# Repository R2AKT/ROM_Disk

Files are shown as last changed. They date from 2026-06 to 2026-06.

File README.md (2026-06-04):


License addendum - https://github.com/R2AKT/ROM_Disk/blob/main/Addendum.txt
# ROM_Disk

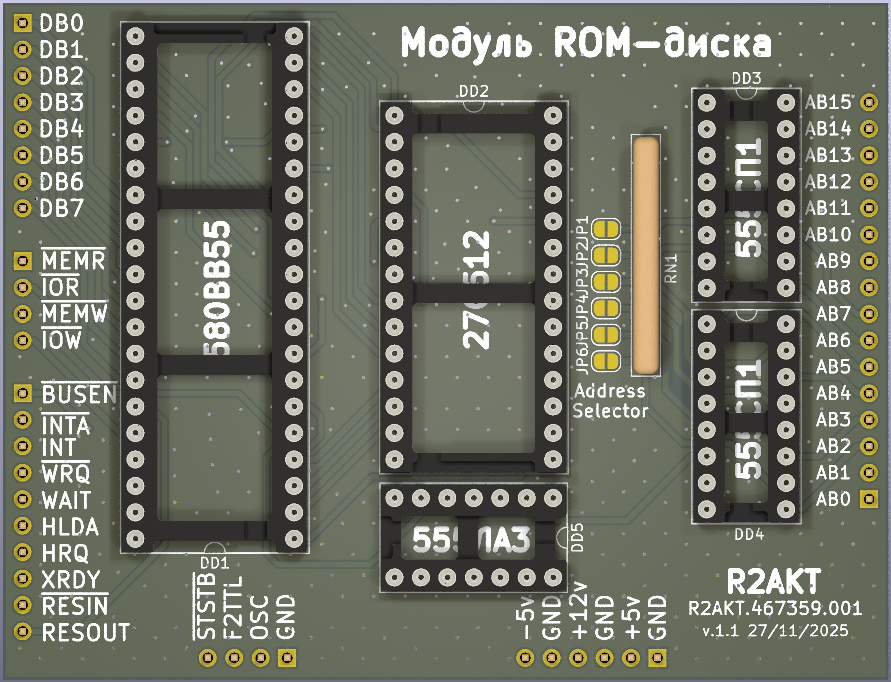
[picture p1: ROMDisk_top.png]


ROM disk board. For Mega-80 (Mega-580) DIY 8-bit micro-computer - https://github.com/R2AKT/Mega-80.

Based on ROM-disk for RADIO-86RK.

Плата ROM-диска. Для самодельной 8-битной микро-ЭВМ - https://github.com/R2AKT/Mega-80.

На основе ROM-диска для РАДИО-86РК.

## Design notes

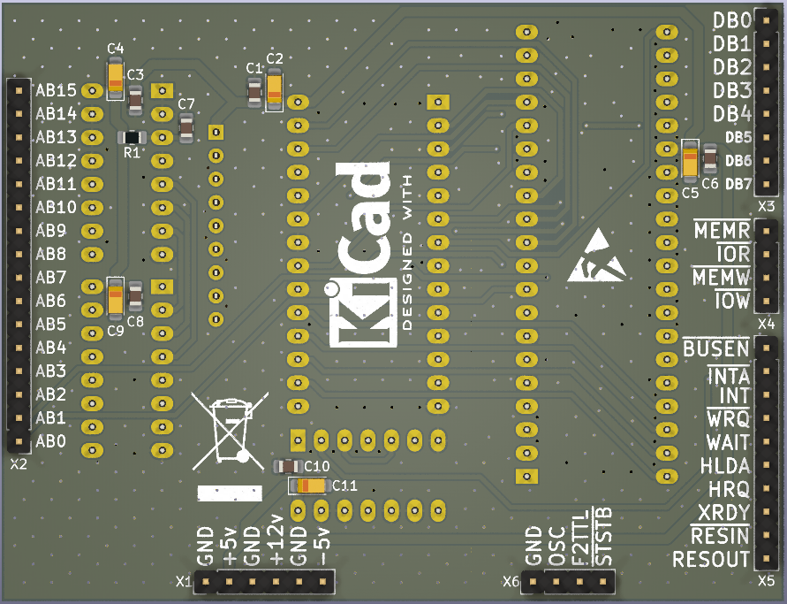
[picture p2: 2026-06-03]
ROMDisk_btn.png

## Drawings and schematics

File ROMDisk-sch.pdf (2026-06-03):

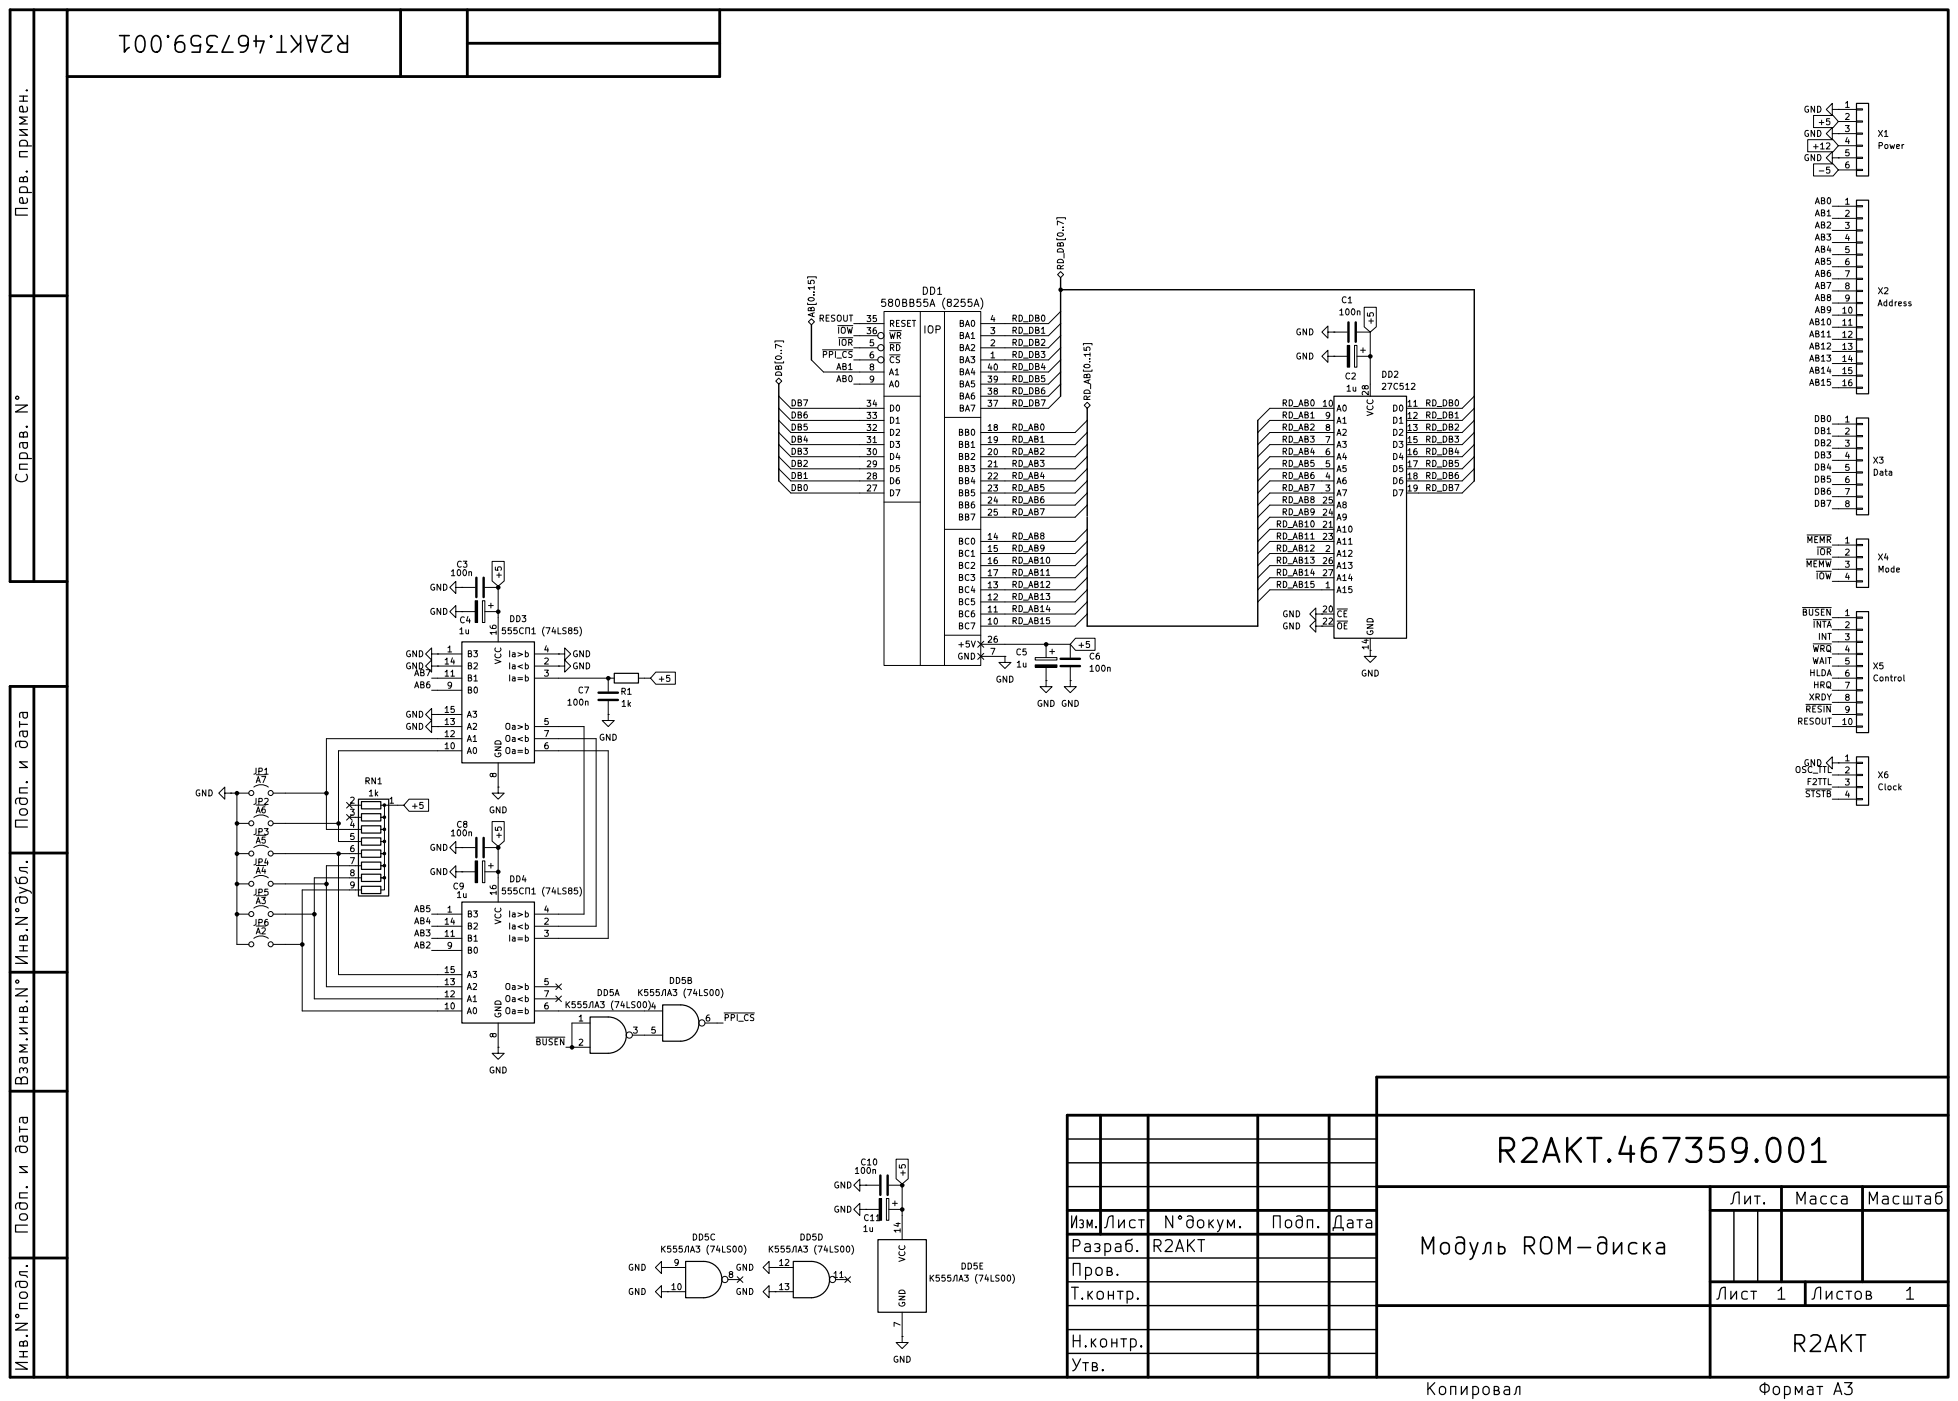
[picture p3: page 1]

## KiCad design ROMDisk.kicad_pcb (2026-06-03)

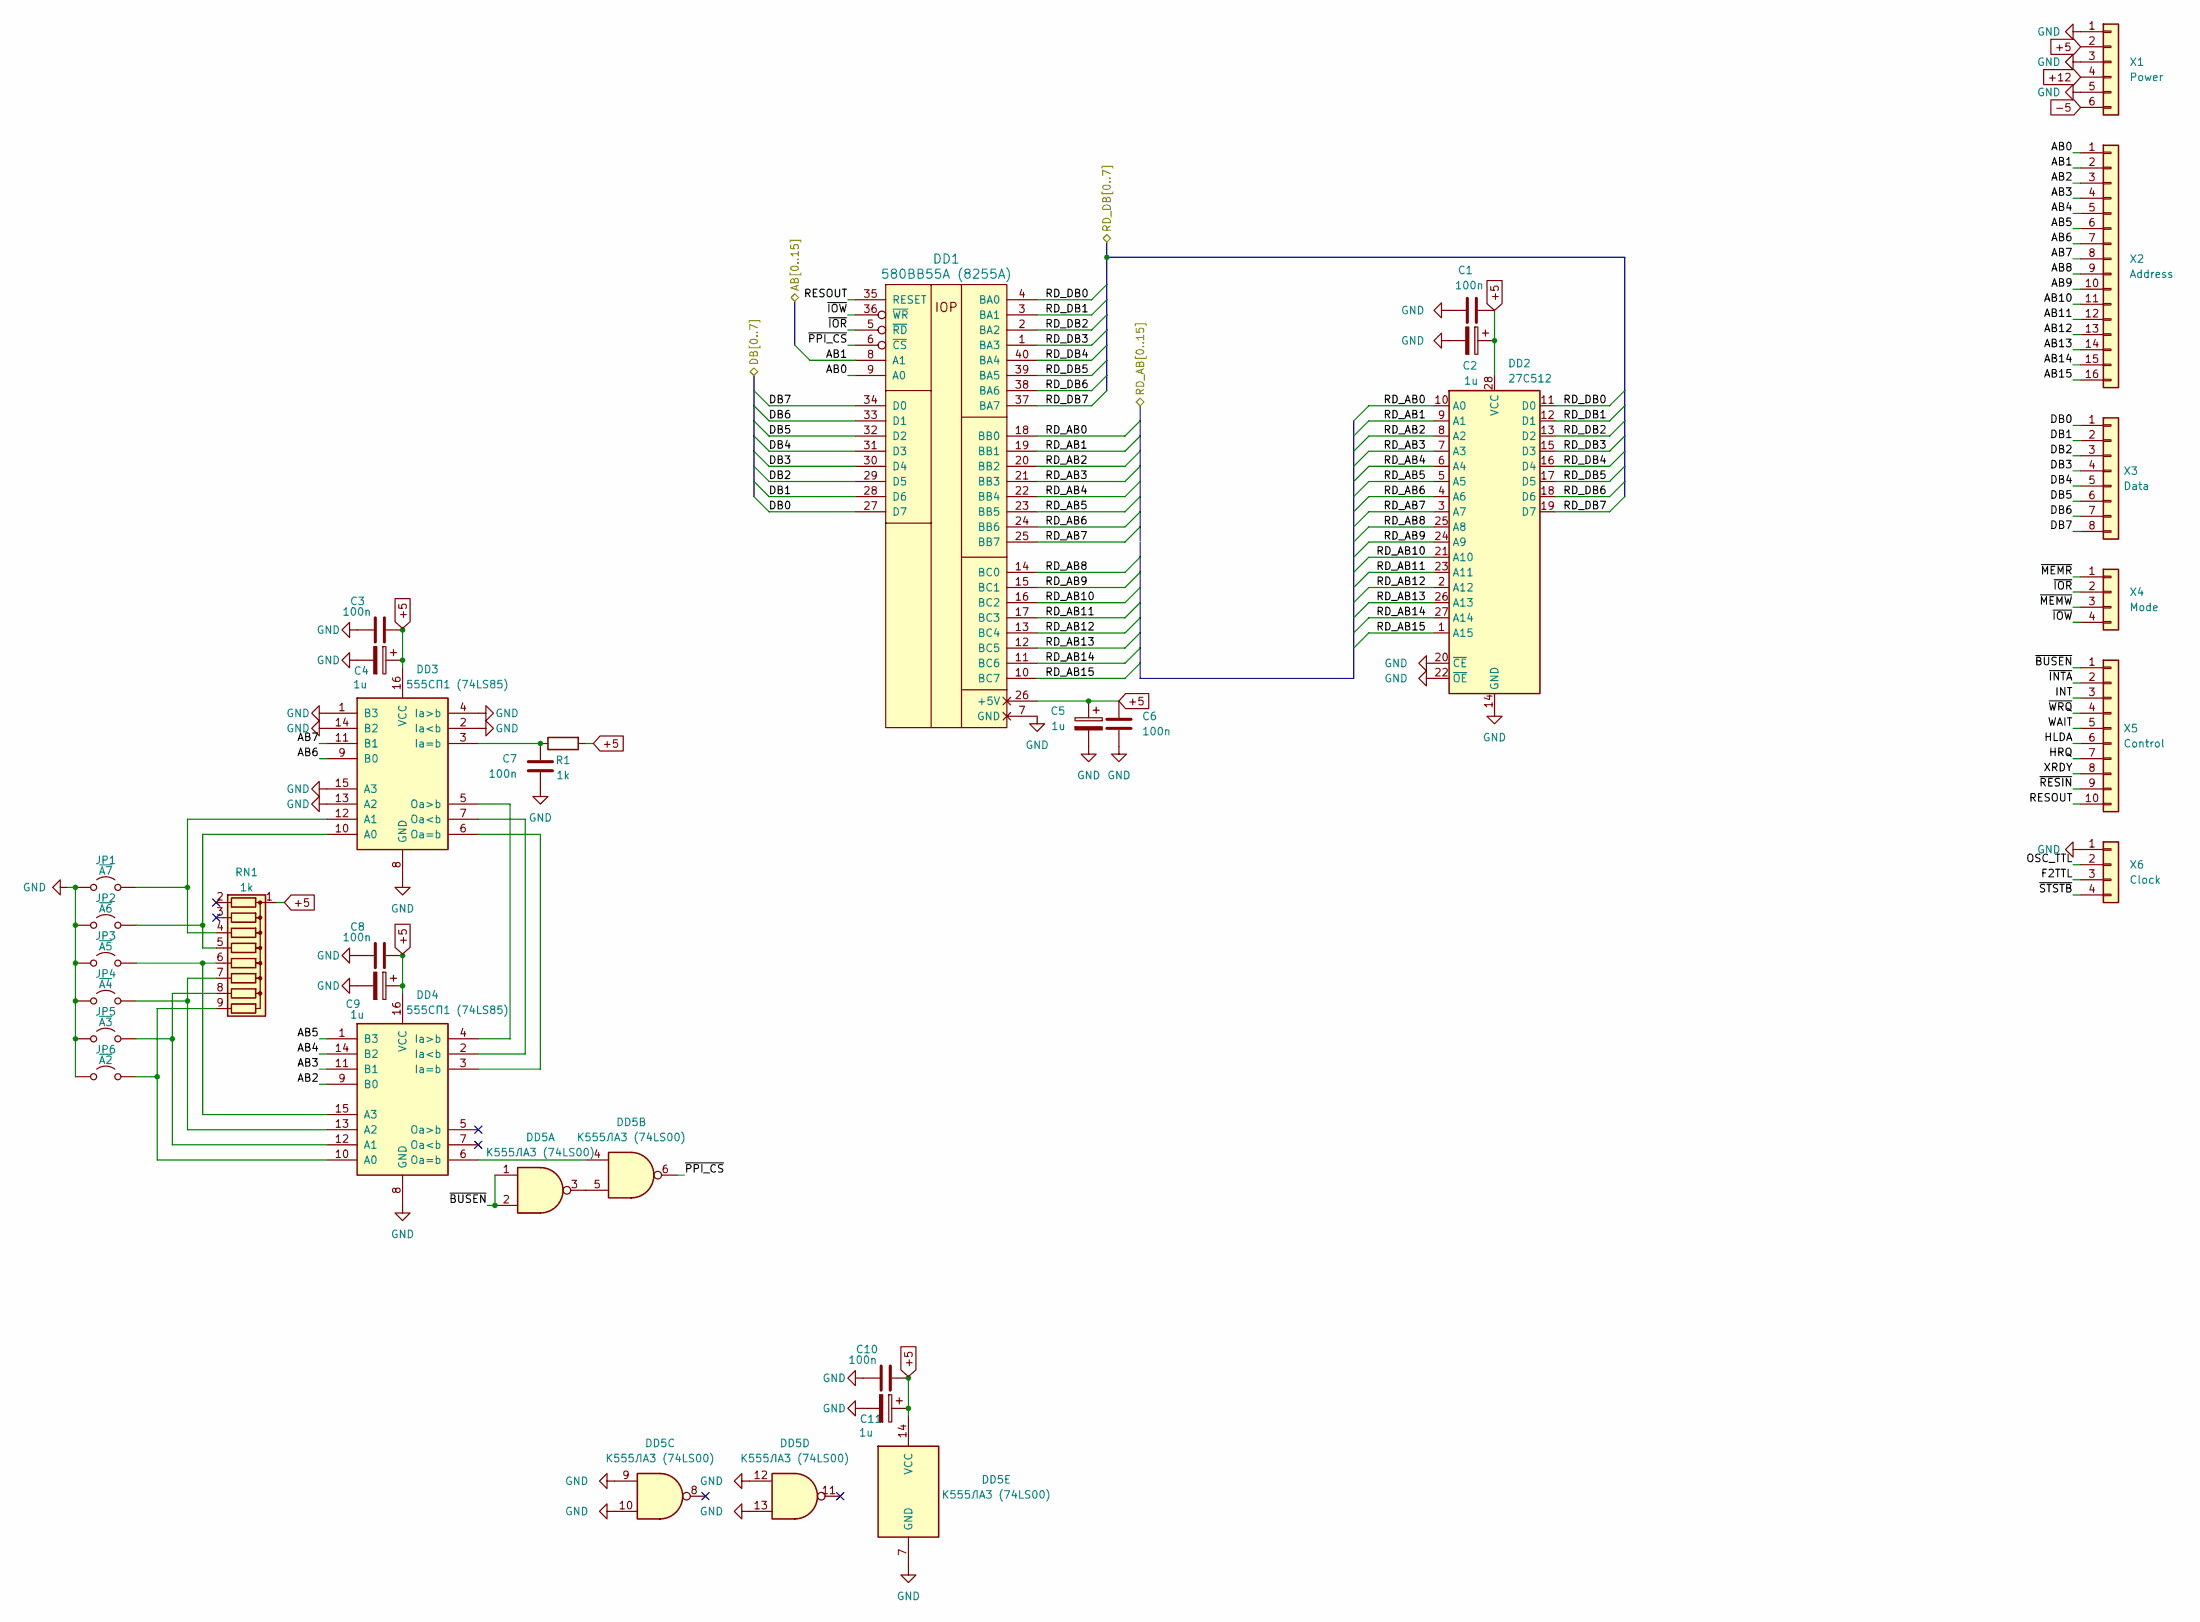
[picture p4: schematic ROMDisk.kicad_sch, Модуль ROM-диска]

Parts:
C1, C3, C6, C7, C8, C10: 100n; C_0805_2012Metric_Pad1.18x1.45mm_HandSolder
C2, C4, C5, C9, C11: 1u; CP_EIA-3216-18_Kemet-A_Pad1.58x1.35mm_HandSolder
DD1: 580ВВ55A (8255A); DIP-40_W15.24mm_Socket_LongPads
DD2: 27C512; DIP-28_W15.24mm_Socket_LongPads
DD3, DD4: 555СП1 (74LS85); DIP-16_W7.62mm_Socket_LongPads
DD5: К555ЛА3 (74LS00); DIP-14_W7.62mm_Socket_LongPads
JP1: ~{A7}; SolderJumper-2_P1.3mm_Open_RoundedPad1.0x1.5mm
JP2: ~{A6}; SolderJumper-2_P1.3mm_Open_RoundedPad1.0x1.5mm
JP3: ~{A5}; SolderJumper-2_P1.3mm_Open_RoundedPad1.0x1.5mm
JP4: ~{A4}; SolderJumper-2_P1.3mm_Open_RoundedPad1.0x1.5mm
JP5: ~{A3}; SolderJumper-2_P1.3mm_Open_RoundedPad1.0x1.5mm
JP6: ~{A2}; SolderJumper-2_P1.3mm_Open_RoundedPad1.0x1.5mm
R1: 1k; R_0805_2012Metric_Pad1.20x1.40mm_HandSolder
RN1: 1k; R_Array_SIP9
X1: Power; PinHeader_1x06_P2.54mm_Vertical
X2: Address; PinHeader_1x16_P2.54mm_Vertical
X3: Data; PinHeader_1x08_P2.54mm_Vertical
X4: Mode; PinHeader_1x04_P2.54mm_Vertical
X5: Control; PinHeader_1x10_P2.54mm_Vertical
X6: Clock; PinHeader_1x04_P2.54mm_Vertical

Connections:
+5: C1.1, C2.1, C3.1, C4.1, C5.1, C6.1, C8.1, C9.1, C10.1, C11.1, DD1.26 (+5V), DD2.28 (VCC), DD3.16 (VCC), DD4.16 (VCC), DD5.14 (VCC), R1.2, RN1.1 (common), X1.2
+12: X1.4
-5: X1.6
/AB0: DD1.9 (A0), X2.1
/AB1: DD1.8 (A1), X2.2
/AB2: DD4.9 (B0), X2.3
/AB3: DD4.11 (B1), X2.4
/AB4: DD4.14 (B2), X2.5
/AB5: DD4.1 (B3), X2.6
/AB6: DD3.9 (B0), X2.7
/AB7: DD3.11 (B1), X2.8
/AB8: X2.9
/AB9: X2.10
/AB10: X2.11
/AB11: X2.12
/AB12: X2.13
/AB13: X2.14
/AB14: X2.15
/AB15: X2.16
/DB0: DD1.27 (D7), X3.1
/DB1: DD1.28 (D6), X3.2
/DB2: DD1.29 (D5), X3.3
/DB3: DD1.30 (D4), X3.4
/DB4: DD1.31 (D3), X3.5
/DB5: DD1.32 (D2), X3.6
/DB6: DD1.33 (D1), X3.7
/DB7: DD1.34 (D0), X3.8
/F2TTL: X6.3
/HLDA: X5.6
/HRQ: X5.7
/INT: X5.3
/OSC_TTL: X6.2
/RD_AB0: DD1.18 (BB0), DD2.10 (A0)
/RD_AB1: DD1.19 (BB1), DD2.9 (A1)
/RD_AB2: DD1.20 (BB2), DD2.8 (A2)
/RD_AB3: DD1.21 (BB3), DD2.7 (A3)
/RD_AB4: DD1.22 (BB4), DD2.6 (A4)
/RD_AB5: DD1.23 (BB5), DD2.5 (A5)
/RD_AB6: DD1.24 (BB6), DD2.4 (A6)
/RD_AB7: DD1.25 (BB7), DD2.3 (A7)
/RD_AB8: DD1.14 (BC0), DD2.25 (A8)
/RD_AB9: DD1.15 (BC1), DD2.24 (A9)
/RD_AB10: DD1.16 (BC2), DD2.21 (A10)
/RD_AB11: DD1.17 (BC3), DD2.23 (A11)
/RD_AB12: DD1.13 (BC4), DD2.2 (A12)
/RD_AB13: DD1.12 (BC5), DD2.26 (A13)
/RD_AB14: DD1.11 (BC6), DD2.27 (A14)
/RD_AB15: DD1.10 (BC7), DD2.1 (A15)
/RD_DB0: DD1.4 (BA0), DD2.11 (D0)
/RD_DB1: DD1.3 (BA1), DD2.12 (D1)
/RD_DB2: DD1.2 (BA2), DD2.13 (D2)
/RD_DB3: DD1.1 (BA3), DD2.15 (D3)
/RD_DB4: DD1.40 (BA4), DD2.16 (D4)
/RD_DB5: DD1.39 (BA5), DD2.17 (D5)
/RD_DB6: DD1.38 (BA6), DD2.18 (D6)
/RD_DB7: DD1.37 (BA7), DD2.19 (D7)
/RESOUT: DD1.35 (RESET), X5.10
/WAIT: X5.5
/XRDY: X5.8
/~BUSEN: DD5.1, DD5.2, X5.1
/~INTA: X5.2
/~IOR: DD1.5 (~RD), X4.2
/~IOW: DD1.36 (~WR), X4.4
/~MEMR: X4.1
/~MEMW: X4.3
/~PPI_CS: DD1.6 (~CS), DD5.6
/~RESIN: X5.9
/~STSTB: X6.4
/~WRQ: X5.4
GND: C1.2, C2.2, C3.2, C4.2, C5.2, C6.2, C7.2, C8.2, C9.2, C10.2, C11.2, DD1.7 (GND), DD2.14 (GND), DD2.20 (~CE), DD2.22 (~OE), DD3.1 (B3), DD3.2 (Ia<b), DD3.4 (Ia>b), DD3.8 (GND), DD3.13 (A2), DD3.14 (B2), DD3.15 (A3), DD4.8 (GND), DD5.7 (GND), DD5.9, DD5.10, DD5.12, DD5.13, JP1.1 (A), JP2.1 (A), JP3.1 (A), JP4.1 (A), JP5.1 (A), JP6.1 (A), X1.1, X1.3, X1.5, X6.1
unnamed: DD3.10 (A0), JP2.2 (B), RN1.5 (R4)
unnamed: DD3.12 (A1), JP1.2 (B), RN1.4 (R3)
unnamed: C7.1, DD3.3 (Ia=b), R1.1
unnamed: DD3.7 (Oa<b), DD4.2 (Ia<b)
unnamed: DD3.6 (Oa=b), DD4.3 (Ia=b)
unnamed: DD3.5 (Oa>b), DD4.4 (Ia>b)
unnamed: DD4.10 (A0), JP6.2 (B), RN1.9 (R8)
unnamed: DD4.12 (A1), JP5.2 (B), RN1.8 (R7)
unnamed: DD4.13 (A2), JP4.2 (B), RN1.7 (R6)
unnamed: DD4.15 (A3), JP3.2 (B), RN1.6 (R5)
unnamed: DD4.6 (Oa=b), DD5.4
unnamed: DD5.3, DD5.5

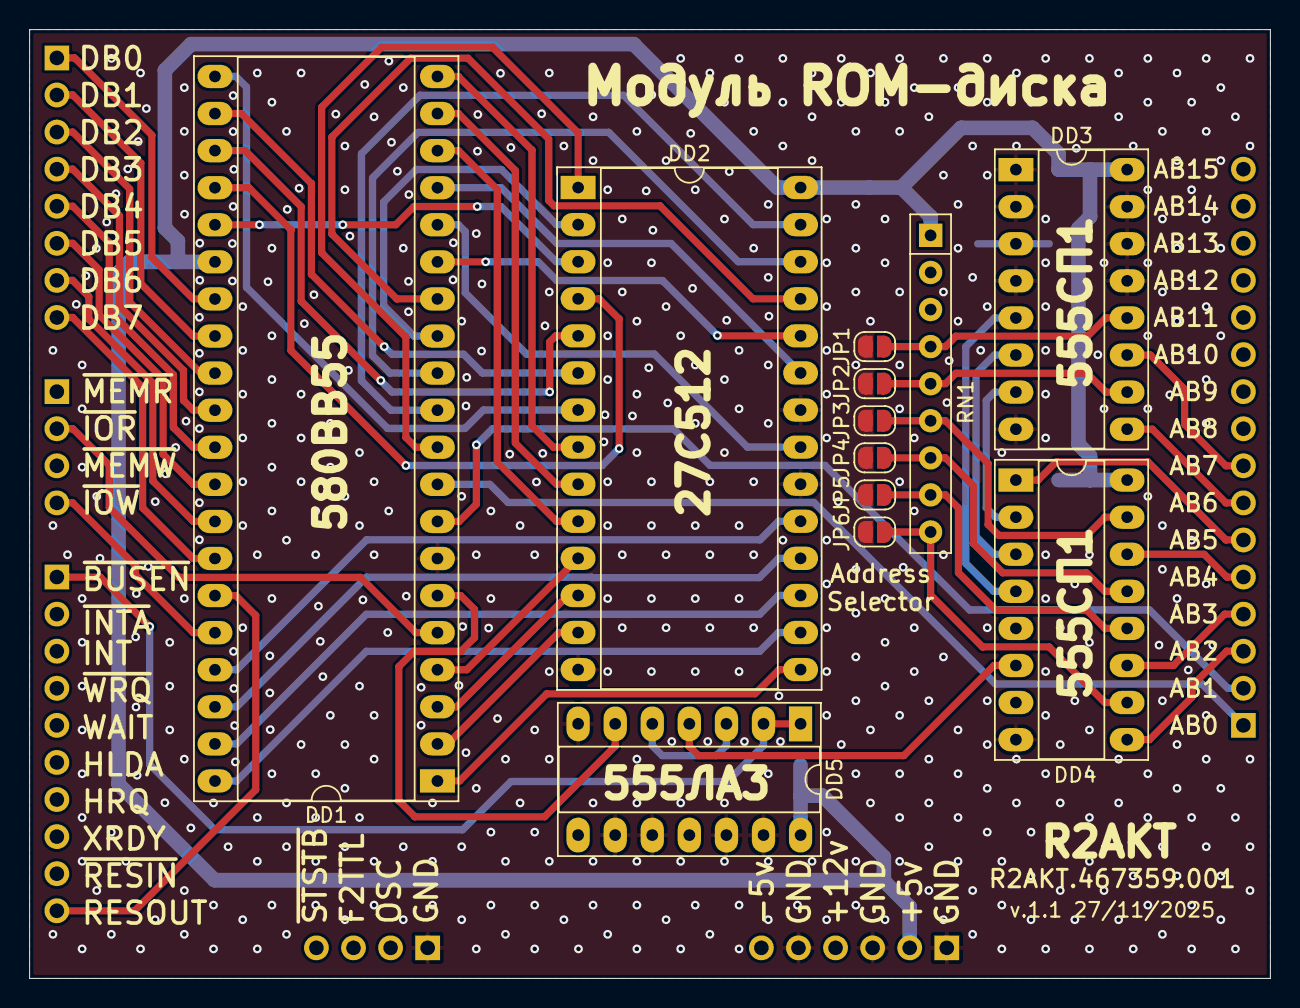
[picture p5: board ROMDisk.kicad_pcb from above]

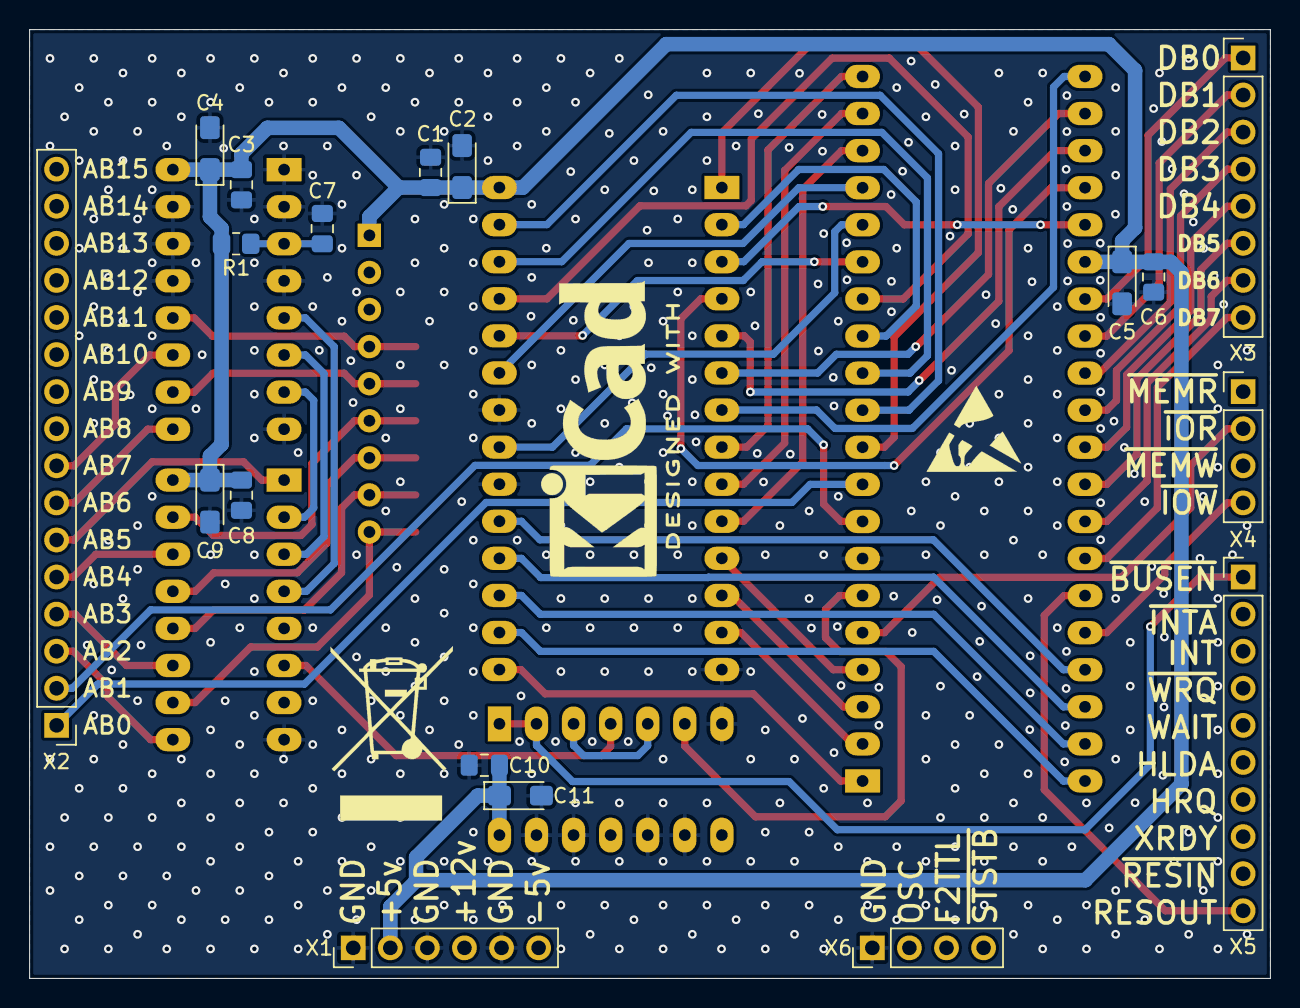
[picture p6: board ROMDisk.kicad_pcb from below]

Board: 2 copper layers, 85.0 x 65.0 mm, 30 parts (18 on the bottom side), 59 nets.

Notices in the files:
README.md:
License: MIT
